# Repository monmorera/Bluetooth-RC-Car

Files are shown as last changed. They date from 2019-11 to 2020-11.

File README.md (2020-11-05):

# Bluetooth-RC-Car
### Bluetooth RC Car project for ECE 196 course

#### About:
This project is to create a bluetooth radio-controlled car. The PCB for the vehicle and remote was created and designed with EAGLE. It was then programmed using Arduino. The remote casing and vehicle parts were created and assembled in SolidWorks. Some parts were 3D printed and others laser cut.

##### Vehicle:
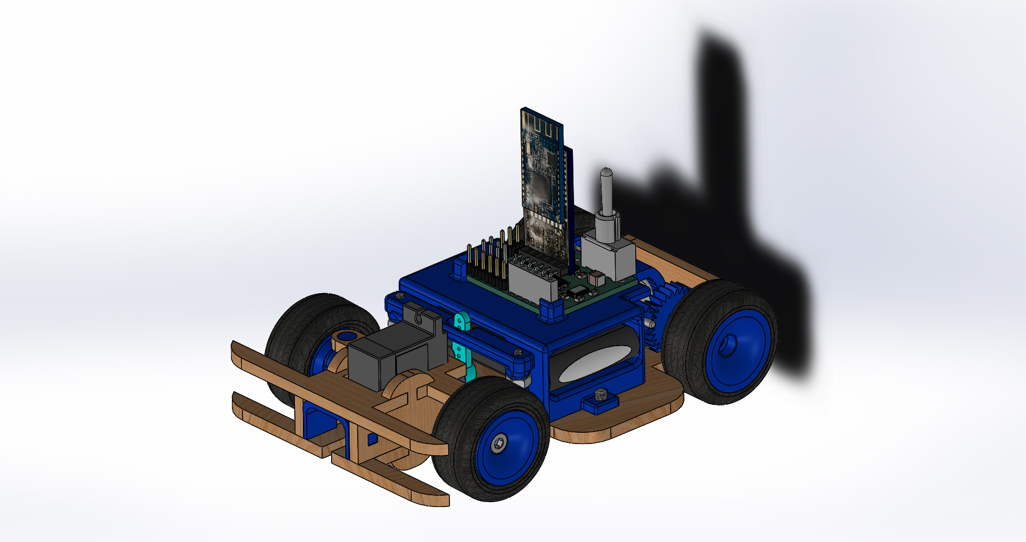
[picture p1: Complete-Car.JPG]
Vehicle


##### Remote:
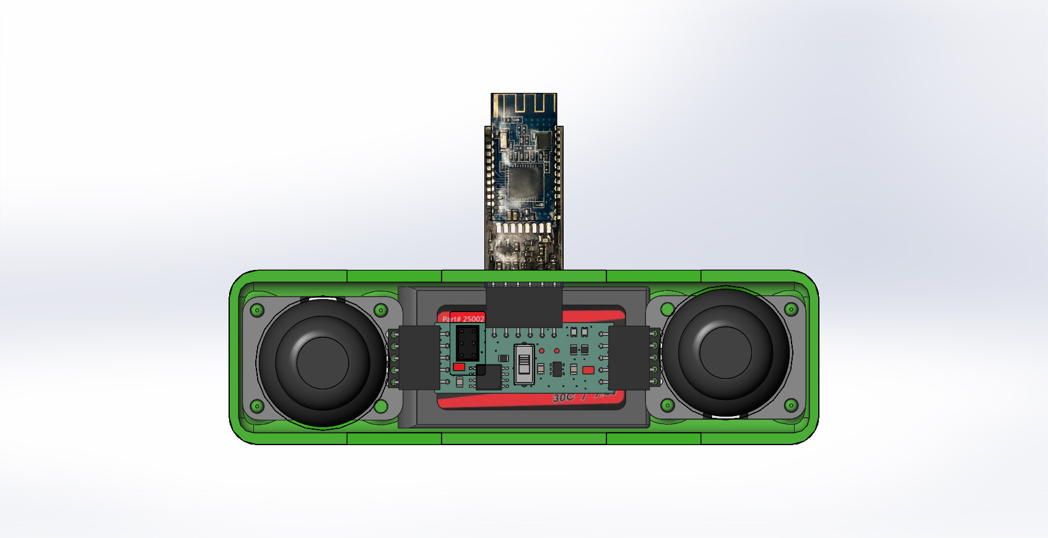
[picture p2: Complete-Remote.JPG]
Remote


##### Final:
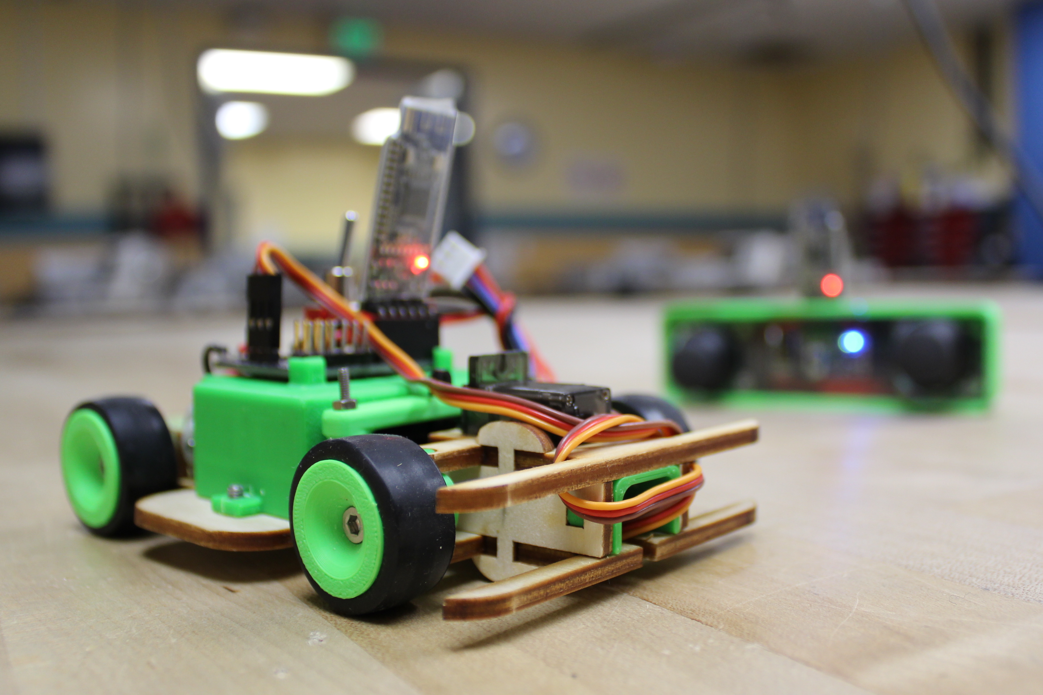
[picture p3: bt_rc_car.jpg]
Final


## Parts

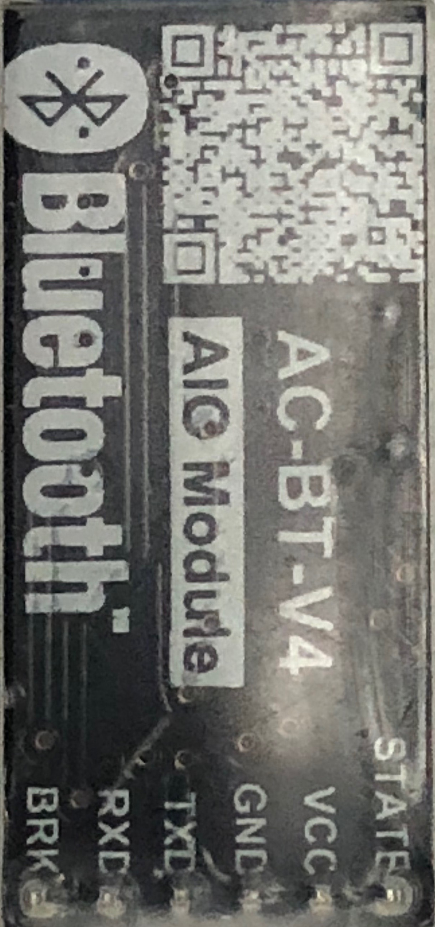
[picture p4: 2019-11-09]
SolidWorks/AddOn_model_parts/Bluetooth_RC/bluetooth_back.JPG

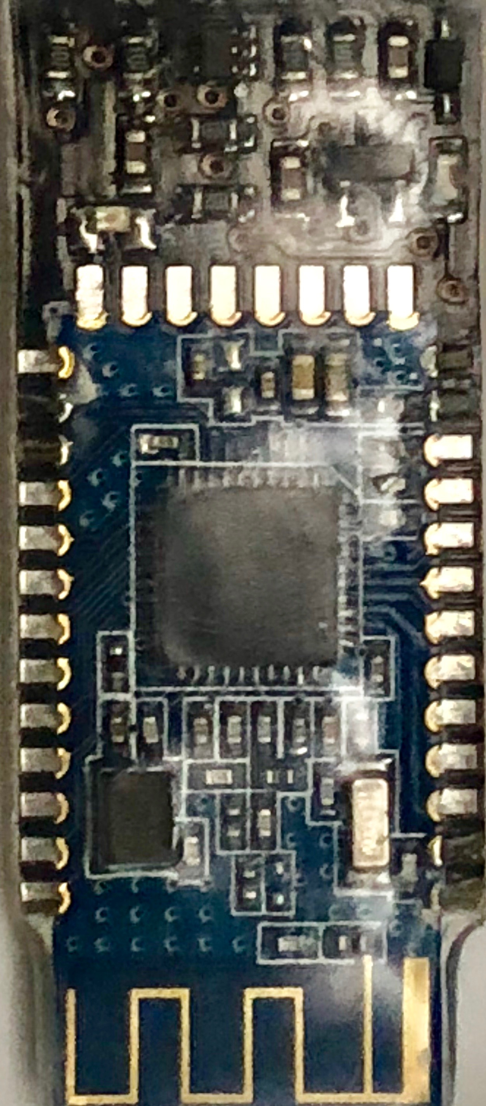
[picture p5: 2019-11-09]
SolidWorks/AddOn_model_parts/Bluetooth_RC/bluetooth_front.JPG

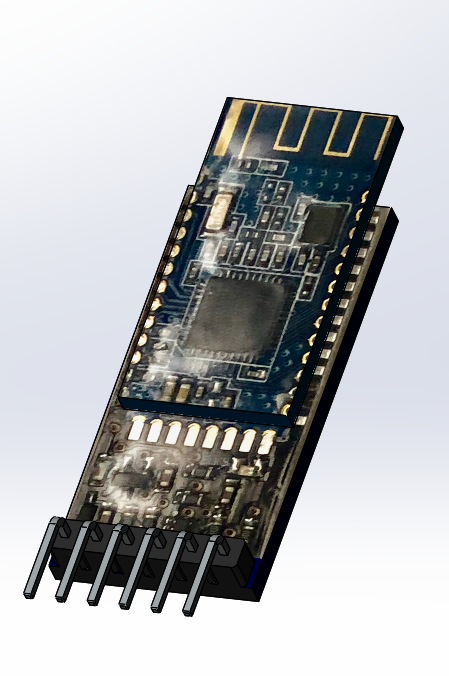
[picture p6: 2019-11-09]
SolidWorks/AddOn_model_parts/Bluetooth_RC/blue.PNG

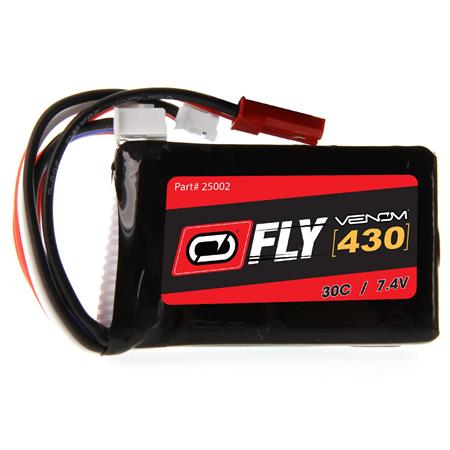
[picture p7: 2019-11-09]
SolidWorks/AddOn_model_parts/ven25002.jpg

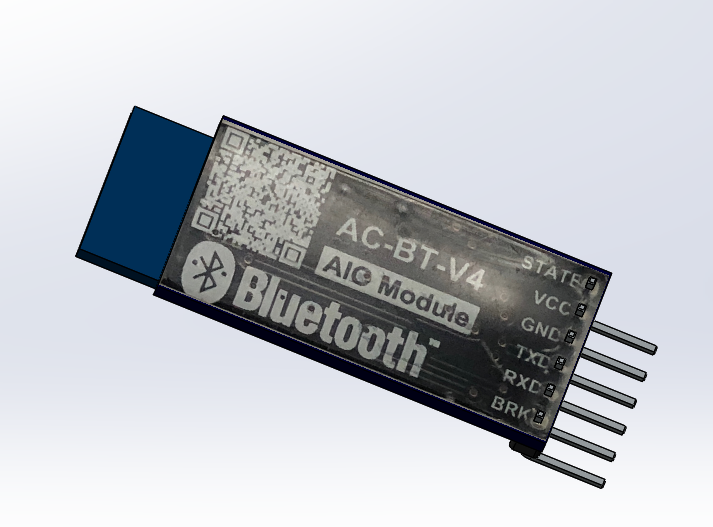
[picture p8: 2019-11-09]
SolidWorks/AddOn_model_parts/Bluetooth_RC/blue_back.PNG

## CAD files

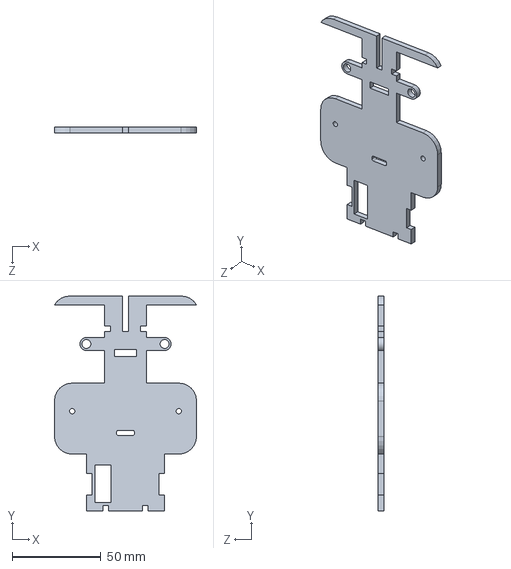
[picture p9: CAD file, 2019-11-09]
SolidWorks/Main Frame.SLDPRT
80.0 x 121.0 x 3.12 mm

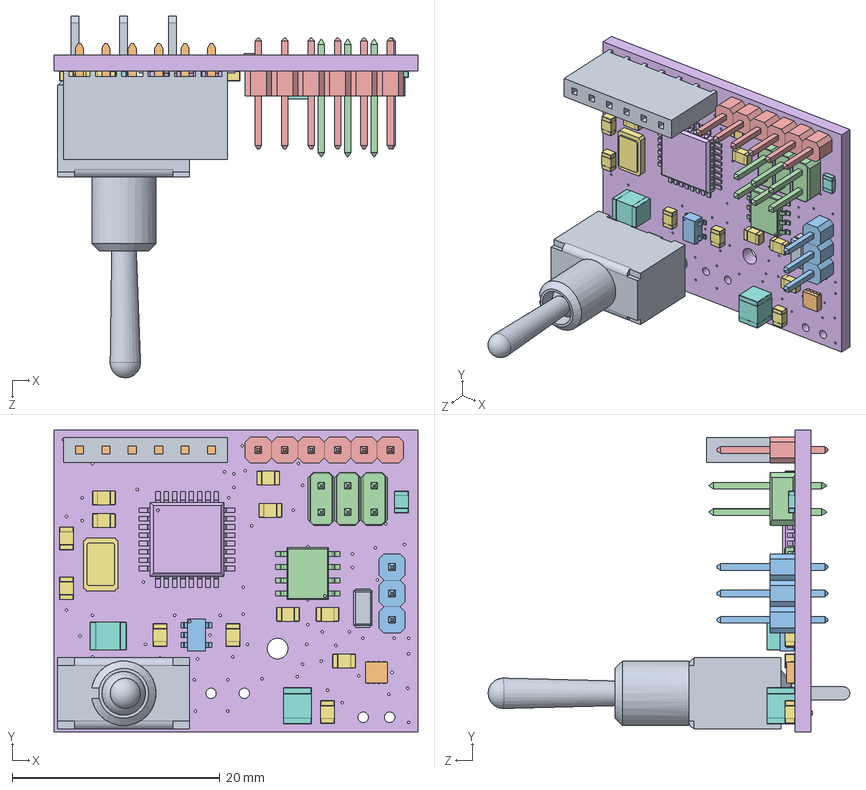
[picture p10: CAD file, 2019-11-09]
SolidWorks/vehicle.SLDASM
35.0 x 29.0 x 34.8 mm
_SSW-106-01-S-S_terminal.step
_SSW-106-01-S-S_pin.step
P(B,C)C01SAAN (1).step x 3
Dual TH withbump format.step x 3
P(B,C)C01SAAN.step x 6
Board.step
1uF_25V.step x 12
10K.step
5A_28V.step
DRV8838D 1.8A.step
MCP1802T-500 300mA_5V.step
BD60GC0WEFJ 1A_6V.step
2PT_GND_TIE.step
ATMEGA328p.step
16 MHz.step
100uF_16V.step x 2
10uF_16V.step

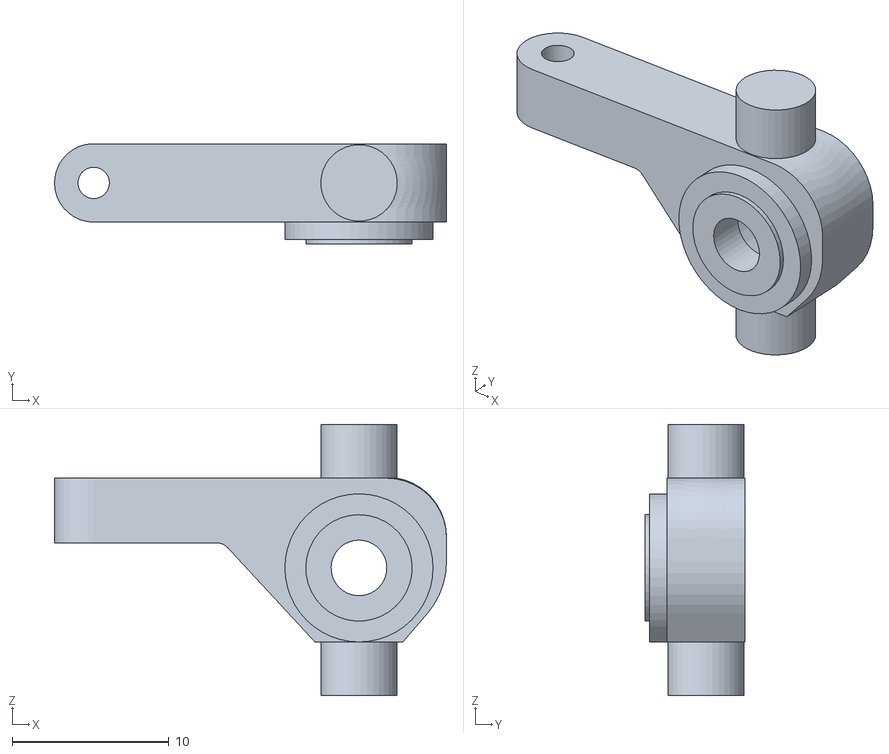
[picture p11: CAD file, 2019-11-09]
SolidWorks/3D print parts of car/ExtendedFrontAxleRightV4.STL
25.0 x 6.41 x 17.3

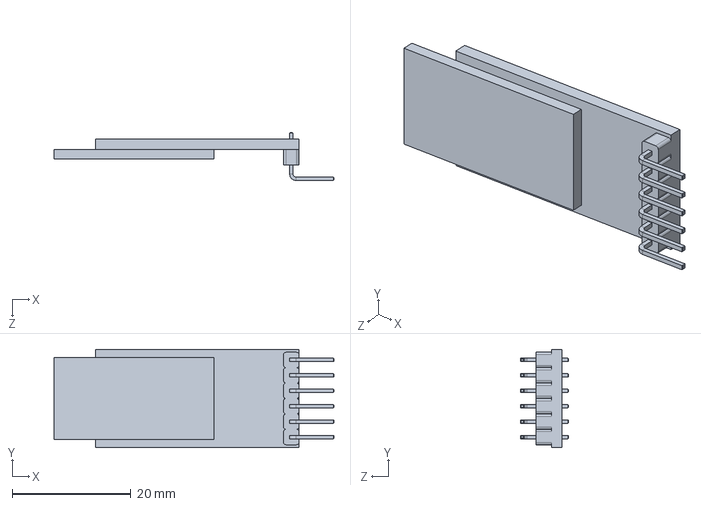
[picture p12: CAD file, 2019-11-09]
SolidWorks/AddOn_model_parts/Bluetooth_RC/Bluetooth_RC.SLDPRT
47.2 x 16.6 x 8.10 mm

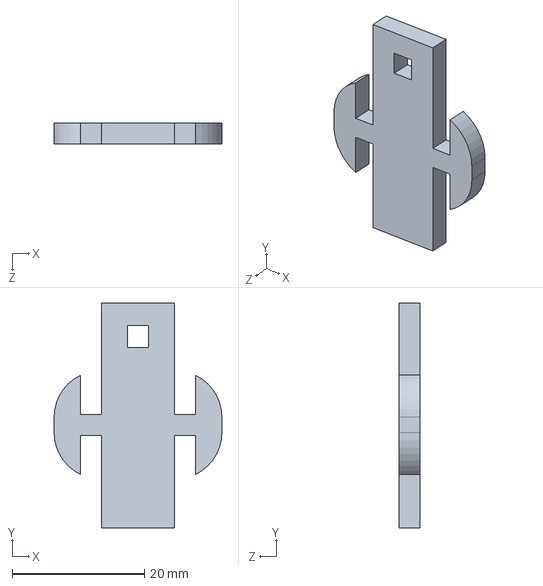
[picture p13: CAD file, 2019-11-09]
SolidWorks/CarFramePartA.SLDPRT
25.4 x 34.0 x 3.12 mm

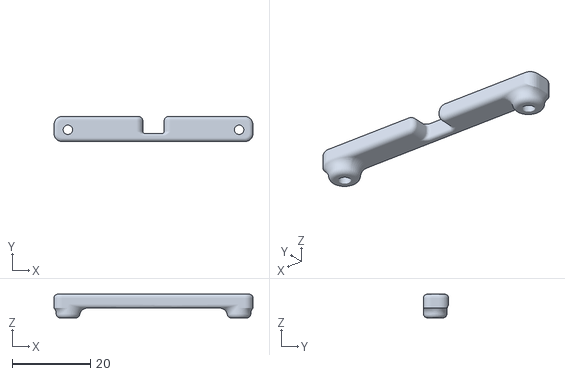
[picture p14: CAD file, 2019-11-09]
SolidWorks/3D print parts of car/ServoMountV7.STL
51.0 x 6.40 x 6.10

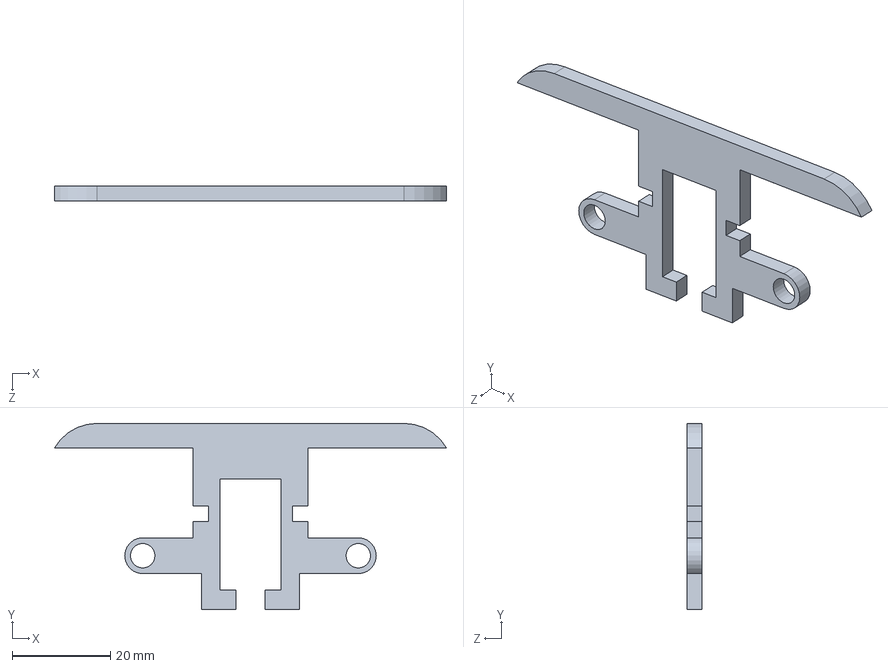
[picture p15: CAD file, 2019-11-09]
SolidWorks/CarFramePartD.SLDPRT
80.0 x 38.0 x 3.12 mm

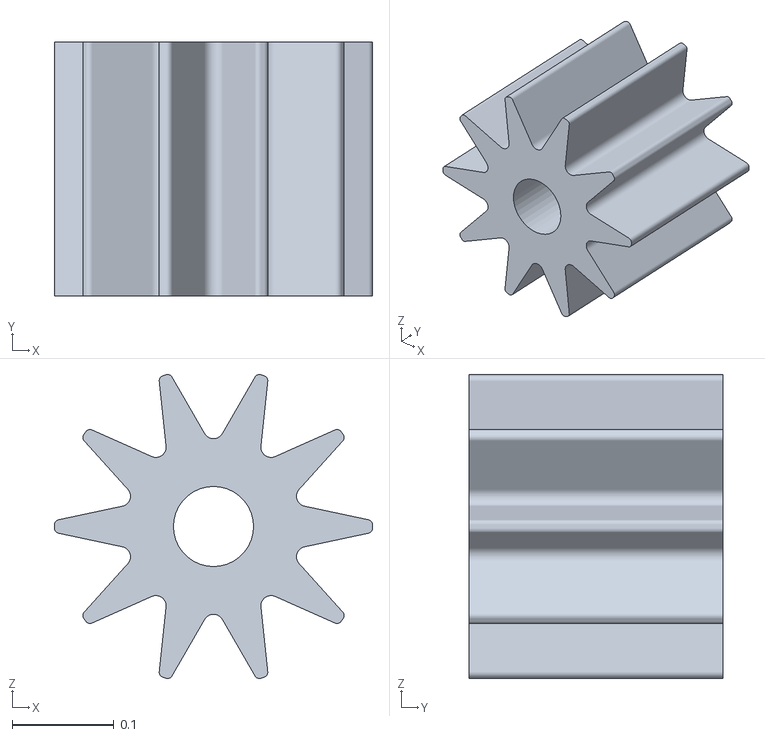
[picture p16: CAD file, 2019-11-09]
SolidWorks/3D print parts of car/motor_gear.STL
0.312 x 0.25 x 0.299

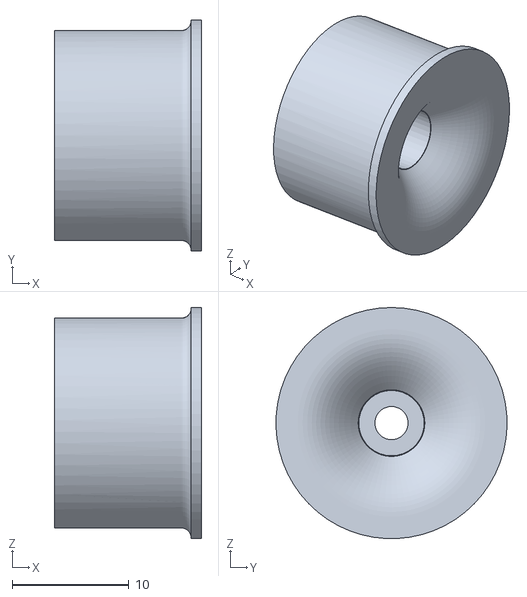
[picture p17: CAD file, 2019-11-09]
SolidWorks/3D print parts of car/FrontWheelV7.STL
12.6 x 19.8 x 19.8

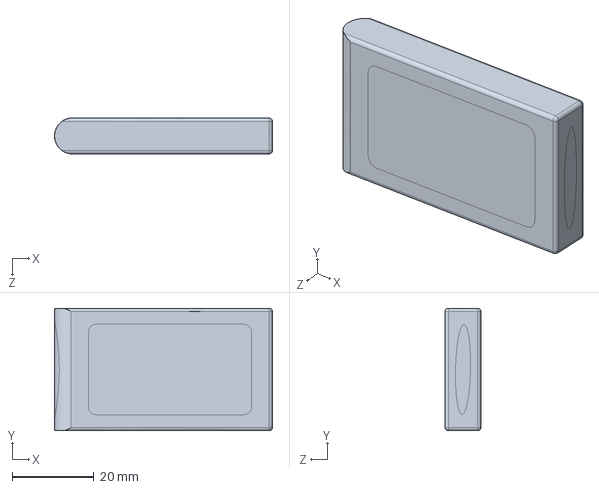
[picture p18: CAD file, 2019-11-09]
SolidWorks/AddOn_model_parts/Battery.SLDPRT
53.4 x 30.0 x 8.81 mm

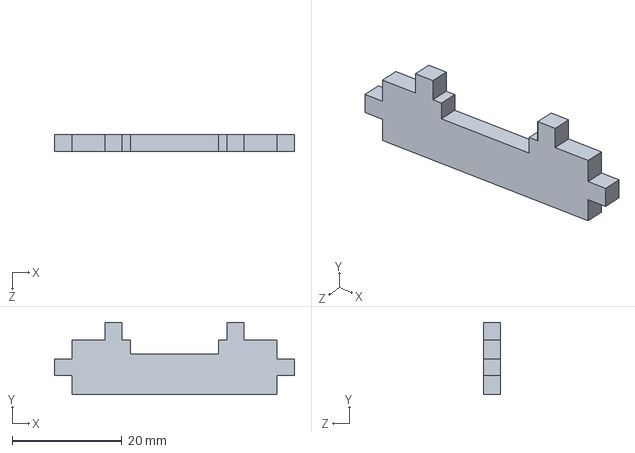
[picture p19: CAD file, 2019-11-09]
SolidWorks/CarFramePartC.SLDPRT
43.8 x 13.2 x 3.12 mm

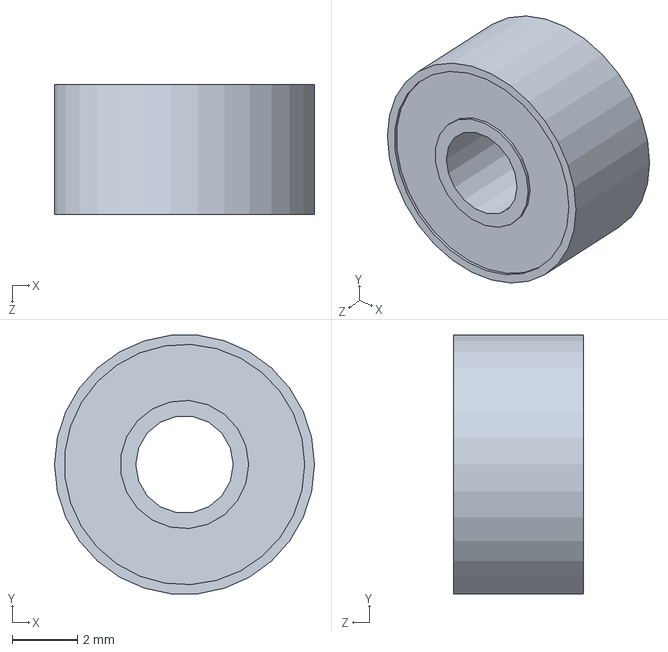
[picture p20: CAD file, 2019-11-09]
SolidWorks/AddOn_model_parts/Bearing.SLDPRT
8.00 x 7.96 x 4.00 mm

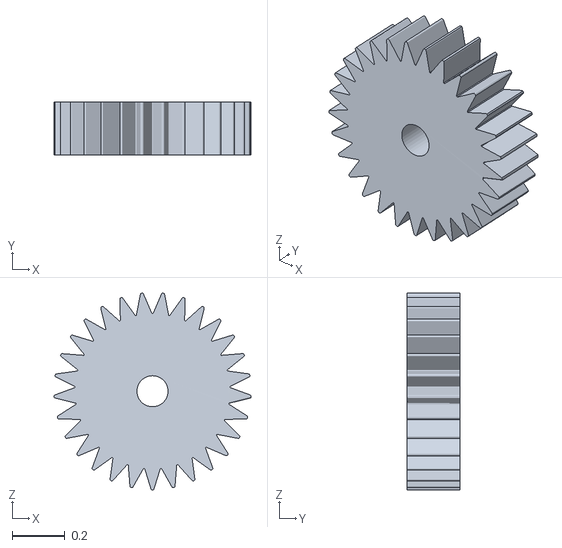
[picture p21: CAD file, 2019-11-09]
SolidWorks/3D print parts of car/driveGearV1.1.STL
0.749 x 0.2 x 0.748

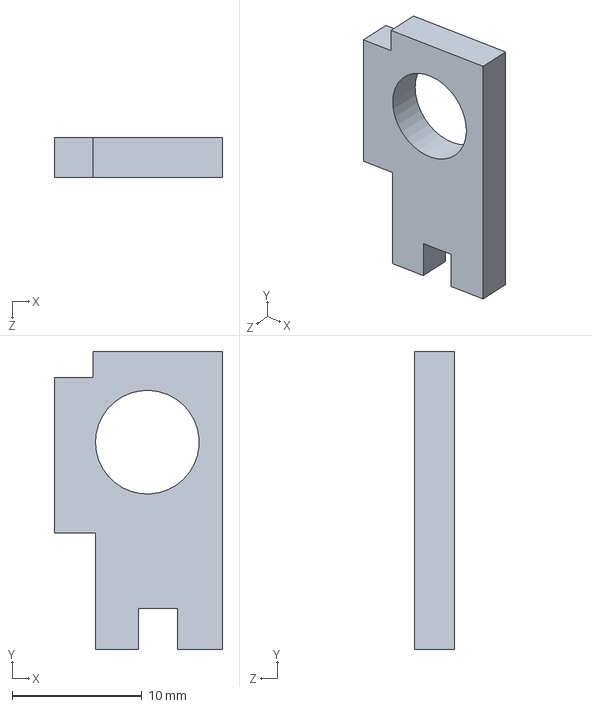
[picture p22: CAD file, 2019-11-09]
SolidWorks/CarFramePartB.SLDPRT
13.0 x 23.0 x 3.12 mm

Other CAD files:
SolidWorks/3D print parts of car/ExtendedFrontAxleLeftV4.STL
SolidWorks/3D print parts of car/PCBsupportV3.STL
SolidWorks/AddOn_model_parts/joy_stick_BTRC.SLDPRT
SolidWorks/3D print parts of car/motorMountV2.STL
SolidWorks/3D print parts of car/BackWheelV7.STL
SolidWorks/3D print parts of car/DCmotor_mountV4.STL
SolidWorks/3D print parts of car/FrontFlexConnectorV1.STL
SolidWorks/AddOn_model_parts/60mmBolt.SLDPRT
SolidWorks/AddOn_model_parts/BTRC DC motor.SLDPRT
SolidWorks/AddOn_model_parts/Buu tire v2.SLDPRT
SolidWorks/AddOn_model_parts/M2_nut.SLDPRT
SolidWorks/AddOn_model_parts/M2_washer.SLDPRT
SolidWorks/AddOn_model_parts/M2x14mm_Screw.SLDPRT
SolidWorks/AddOn_model_parts/M3_nut.SLDPRT
SolidWorks/AddOn_model_parts/M3_washer.SLDPRT
SolidWorks/AddOn_model_parts/M3x16mm_Screw.SLDPRT
SolidWorks/AddOn_model_parts/M3x60mm_Screw.SLDPRT
SolidWorks/AddOn_model_parts/M3x8mm_Screw.SLDPRT
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

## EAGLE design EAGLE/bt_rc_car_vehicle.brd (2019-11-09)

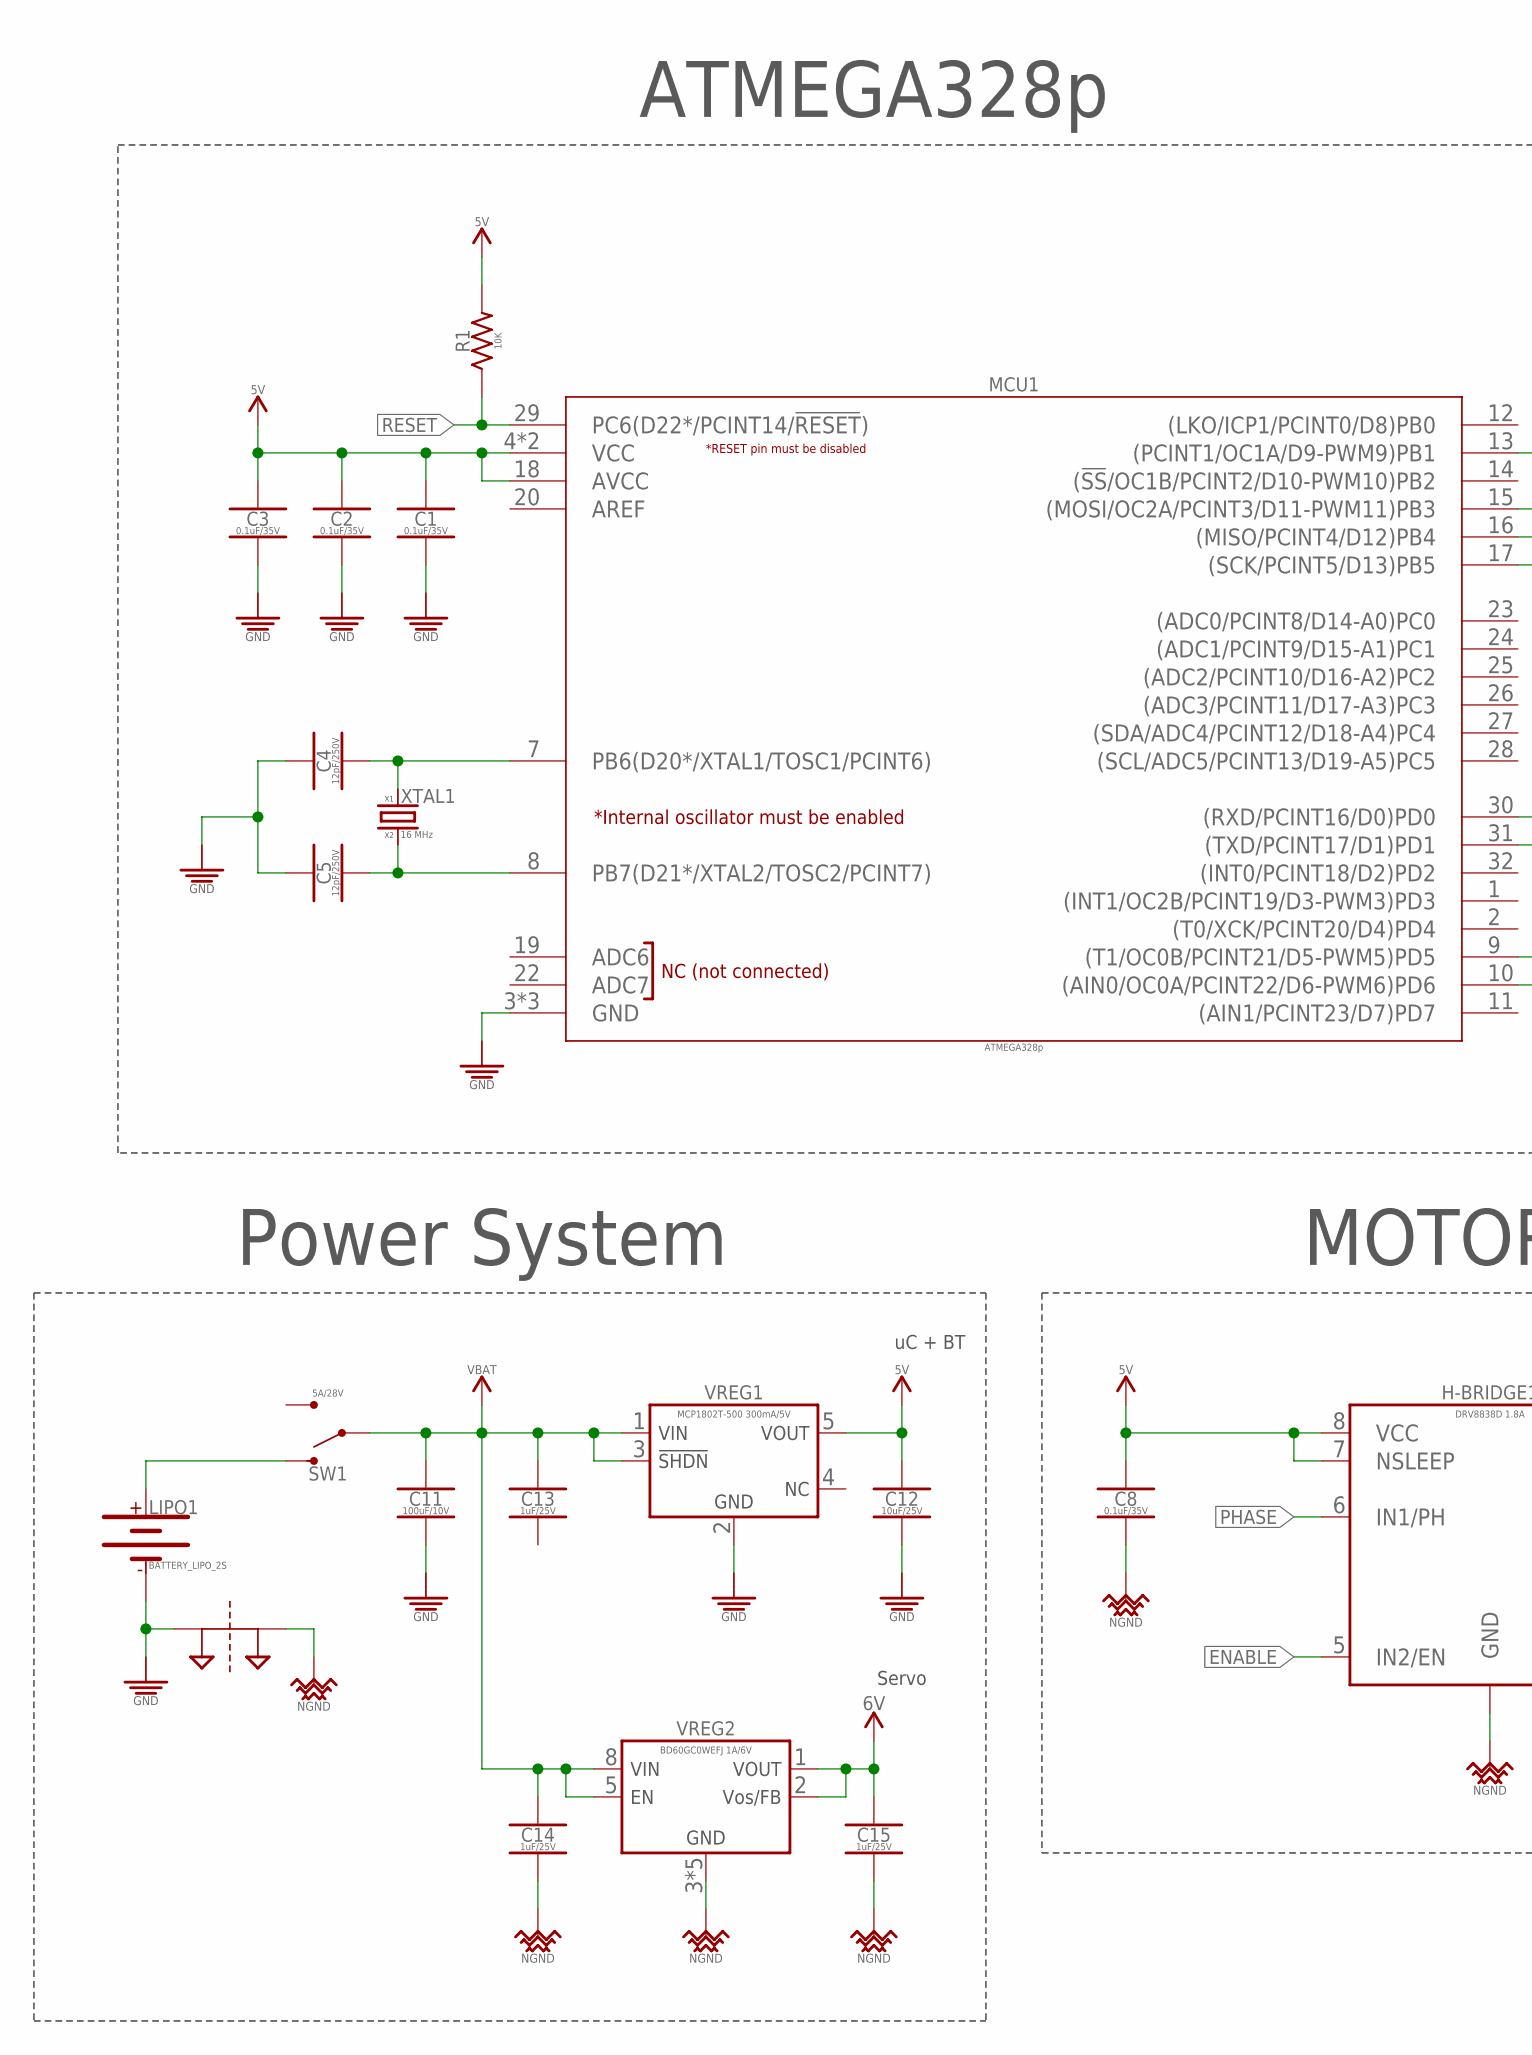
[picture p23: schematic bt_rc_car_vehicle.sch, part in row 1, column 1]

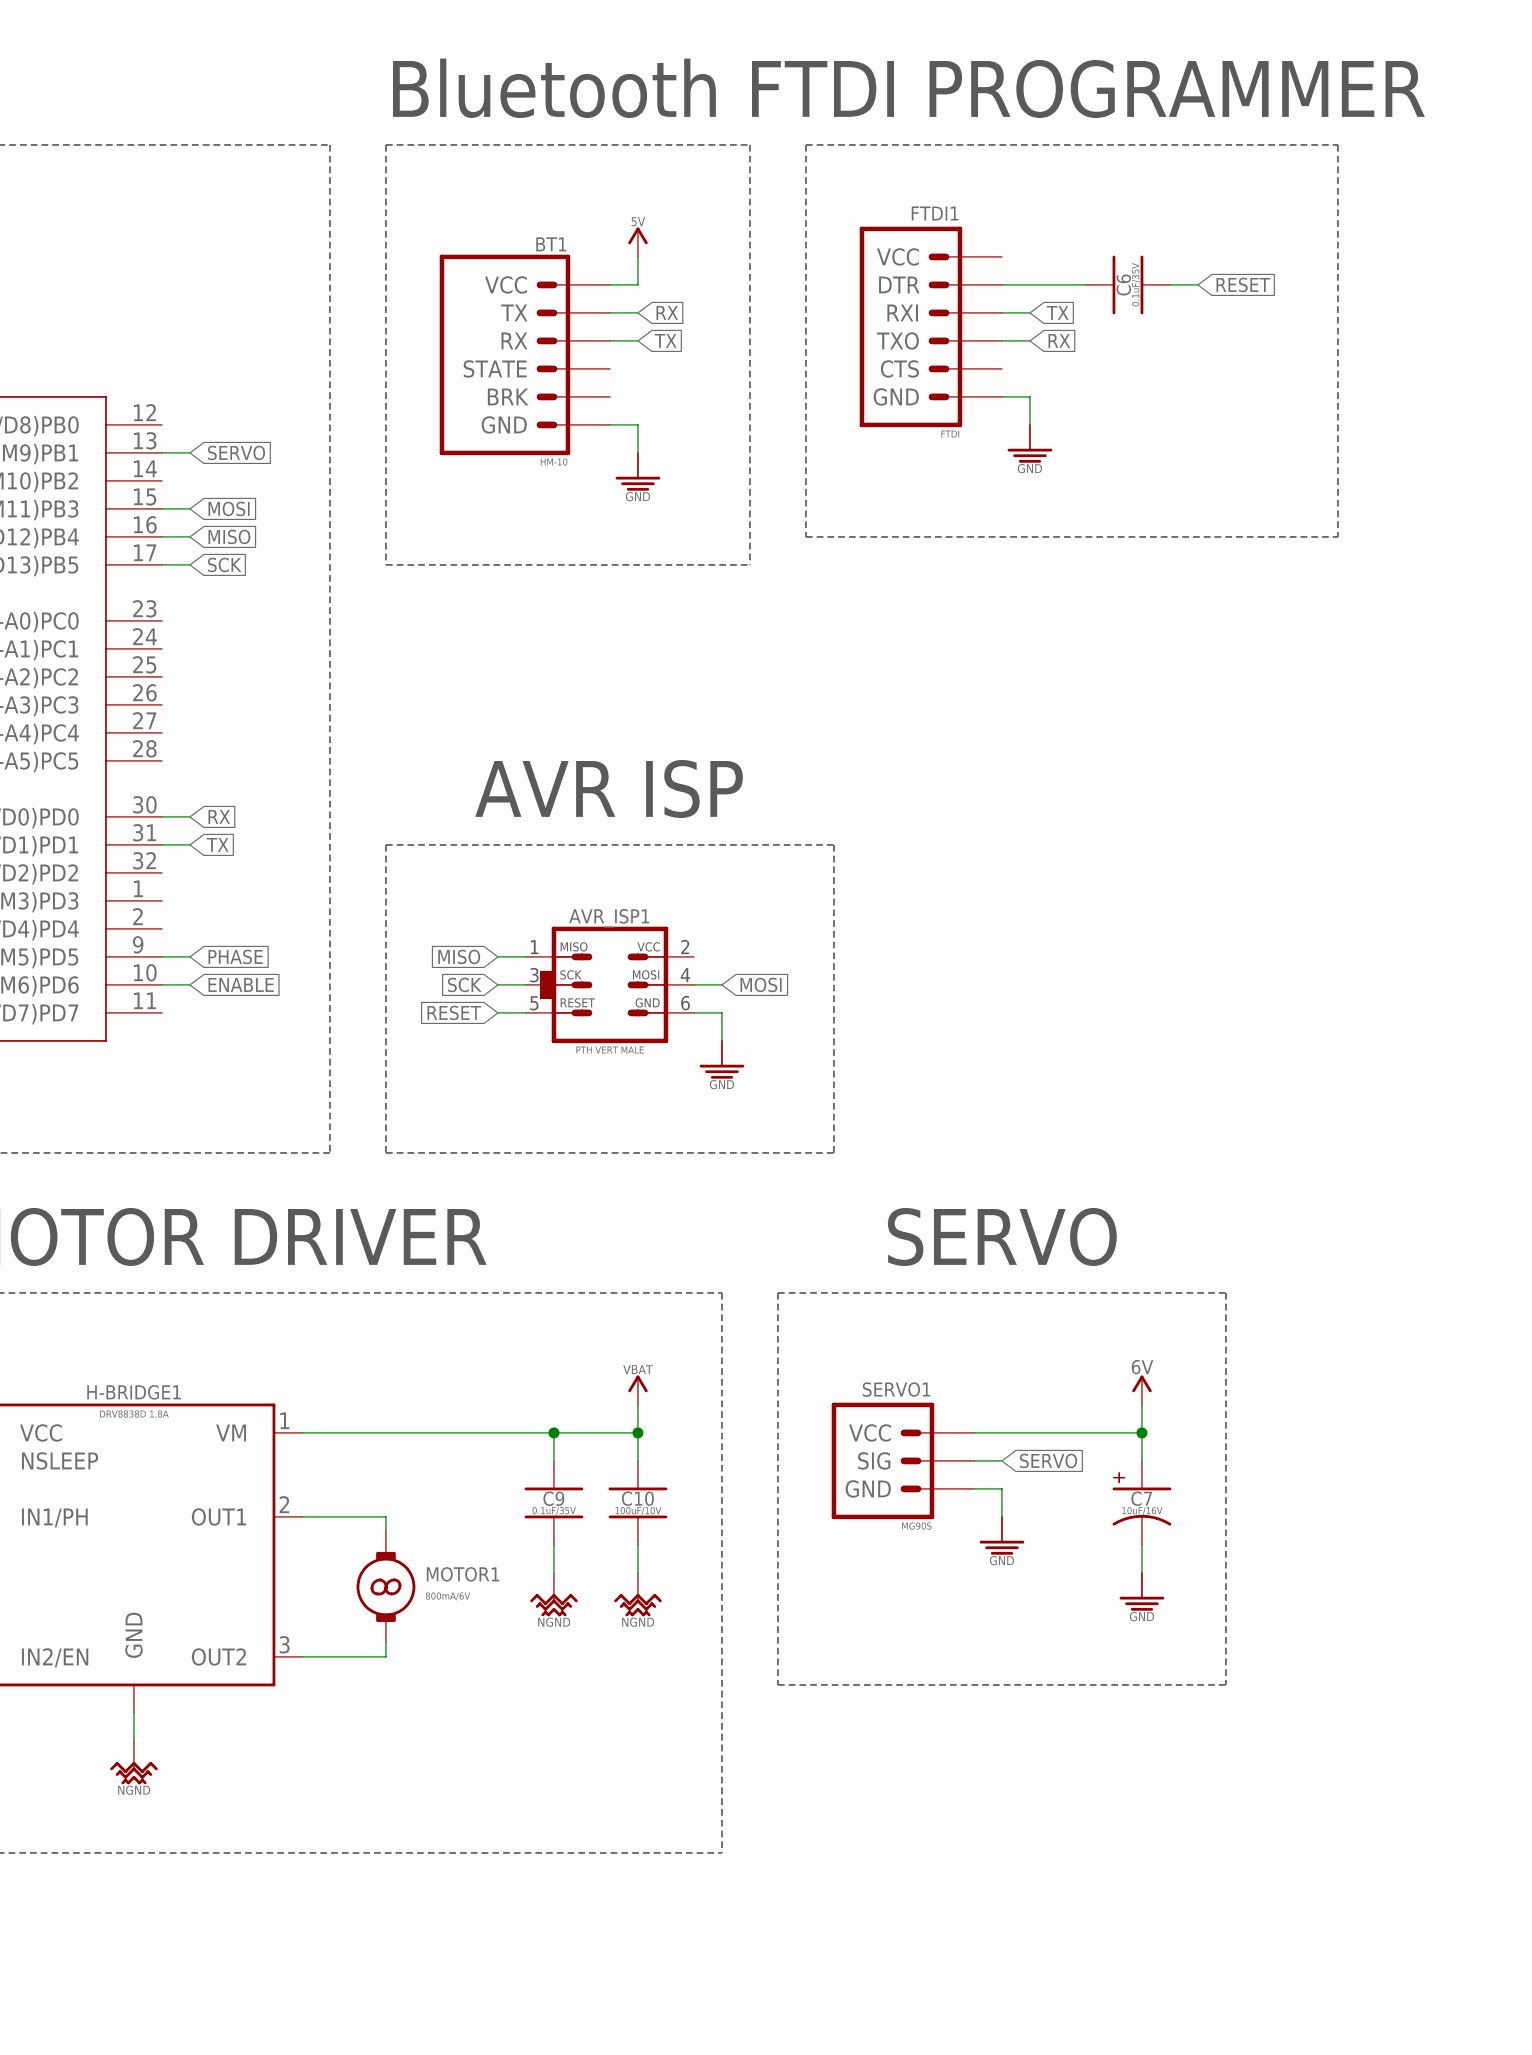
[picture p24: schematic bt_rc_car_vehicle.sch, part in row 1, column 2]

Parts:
AVR_ISP1: PTH VERT MALE; HDRV6W64P254_2X3_762X483X838B_AVR-ISP
BT1: HM-10; HDRVR6W64P254_1X6_1574X254X850B
C1, C2, C3, C6, C8, C9: 0.1uF/35V; CAPC2012X95_SMD-0805
C4, C5: 12pF/250V; CAPC2012X95_SMD-0805
C7: 10uF/16V; CAPMP3216X180_SMD_CAP-TANT-1206
C10, C11: 100uF/10V; CAPC3225X270_SMD-1210
C12: 10uF/25V; CAPC2012X95_SMD-0805
C13, C14, C15: 1uF/25V; CAPC2012X95_SMD-0805
FTDI1: FTDI; HDRV6W64P254_1X6_1524X254X838B_FTDI
H-BRIDGE1: DRV8838D 1.8A; WSON-8-PPAD
LIPO1: BATTERY_LIPO_2S; DUAL_PTH_PADS
MCU1: ATMEGA328p; QFP80P900X900X120-32
MOTOR1: 800mA/6V; CONNECTOR_MOTOR
NET_BRIDGE1: NET_BRIDGE
R1: 10K; RESC2012X60_SMD-0805
SERVO1: MG90S; HDRV3W64P254_1X3_762X254X838B
SW1: 5A/28V; SW_TOGGLE_SPDT_5A-28V_13L-7W
VREG1: MCP1802T-500 300mA/5V; SOT95P280X145-5
VREG2: BD60GC0WEFJ 1A/6V; SOIC127P600X100-8
XTAL1: 16 MHz; OSCCC500X320X110_CRYSTAL

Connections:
5V: BT1.VCC, C1.1, C2.1, C3.1, C8.1, C12.1, H-BRIDGE1.7 (NSLEEP), H-BRIDGE1.8 (VCC), MCU1.4 (VCC), MCU1.6 (VCC), MCU1.18 (AVCC), R1.2, VREG1.5 (VOUT)
6V: C7.A, C15.1, SERVO1.VCC, VREG2.1 (VOUT), VREG2.2 (VOS/FB)
ENABLE: H-BRIDGE1.5 (IN2/EN), MCU1.10 ((AIN0/OC0A/PCINT22/D6-PWM6)PD6)
GND: AVR_ISP1.GND, BT1.GND, C1.2, C2.2, C3.2, C4.1, C5.1, C7.K, C11.2, C12.2, FTDI1.GND, LIPO1.-, MCU1.3 (GND), MCU1.5 (GND), MCU1.21 (GND), NET_BRIDGE1.P$1, SERVO1.GND, VREG1.2 (GND)
MISO: AVR_ISP1.MISO, MCU1.16 ((MISO/PCINT4/D12)PB4)
MOSI: AVR_ISP1.MOSI, MCU1.15 ((MOSI/OC2A/PCINT3/D11-PWM11)PB3)
unnamed: C5.2, MCU1.8 (PB7(D21*/XTAL2/TOSC2/PCINT7)), XTAL1.3 (XTAL2)
unnamed: C4.2, MCU1.7 (PB6(D20*/XTAL1/TOSC1/PCINT6)), XTAL1.1 (XTAL1)
unnamed: C6.1, FTDI1.DTR
unnamed: H-BRIDGE1.2 (OUT1), MOTOR1.+
unnamed: H-BRIDGE1.3 (OUT2), MOTOR1.-
unnamed: LIPO1.+, SW1.S1
NGND: C8.2, C9.2, C10.2, C14.2, C15.2, H-BRIDGE1.4 (GND), H-BRIDGE1.GND, H-BRIDGE1.P$1 (GND), H-BRIDGE1.P$2 (GND), NET_BRIDGE1.P$2, VREG2.3 (GND), VREG2.4 (GND), VREG2.6 (GND), VREG2.7 (GND), VREG2.FIN (GND)
PHASE: H-BRIDGE1.6 (IN1/PH), MCU1.9 ((T1/OC0B/PCINT21/D5-PWM5)PD5)
RESET: AVR_ISP1.RESET, C6.2, MCU1.29 (PC6(D22*/PCINT14/!RESET!)), R1.1
RX: BT1.TX, FTDI1.TX (TXO), MCU1.30 ((RXD/PCINT16/D0)PD0)
SCK: AVR_ISP1.SCK, MCU1.17 ((SCK/PCINT5/D13)PB5)
SERVO: MCU1.13 ((PCINT1/OC1A/D9-PWM9)PB1), SERVO1.SIG
TX: BT1.RX, FTDI1.RX (RXI), MCU1.31 ((TXD/PCINT17/D1)PD1)
VBAT: C9.1, C10.1, C11.1, C13.1, C14.1, H-BRIDGE1.1 (VM), SW1.P, VREG1.1 (VIN), VREG1.3 (!SHDN), VREG2.5 (EN), VREG2.8 (VIN)

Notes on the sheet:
ATMEGA328p
Bluetooth
AVR ISP
FTDI PROGRAMMER
SERVO
MOTOR DRIVER
Power System
Servo
uC + BT

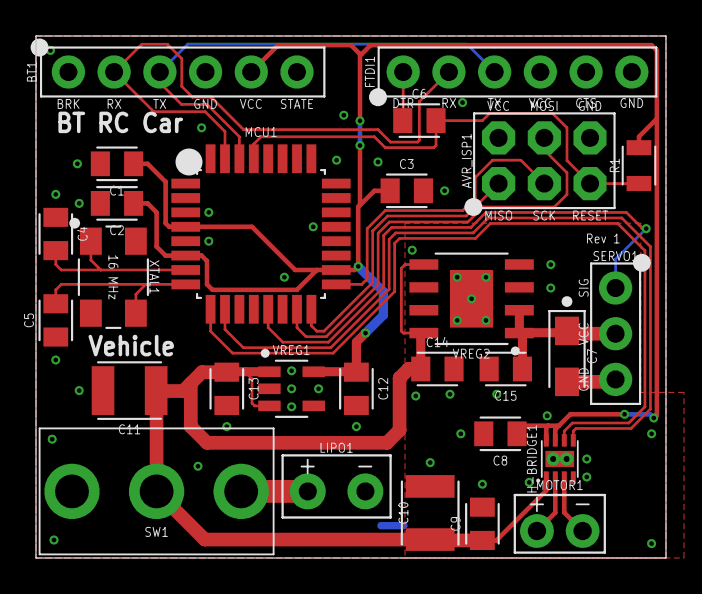
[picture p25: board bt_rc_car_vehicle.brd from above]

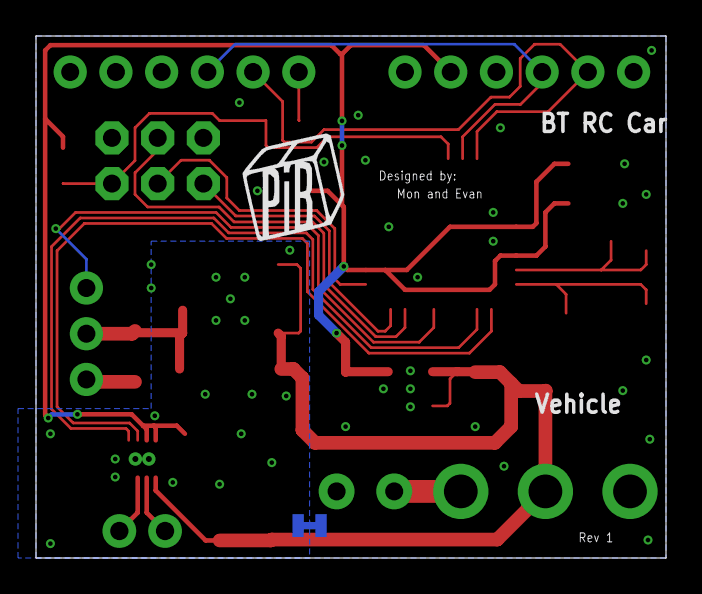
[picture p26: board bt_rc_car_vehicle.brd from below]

Board: 2 copper layers, 35.0 x 29.0 mm, 30 parts (2 on the bottom side), 20 nets.

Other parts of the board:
U$1: PIB_LOGO_10MM

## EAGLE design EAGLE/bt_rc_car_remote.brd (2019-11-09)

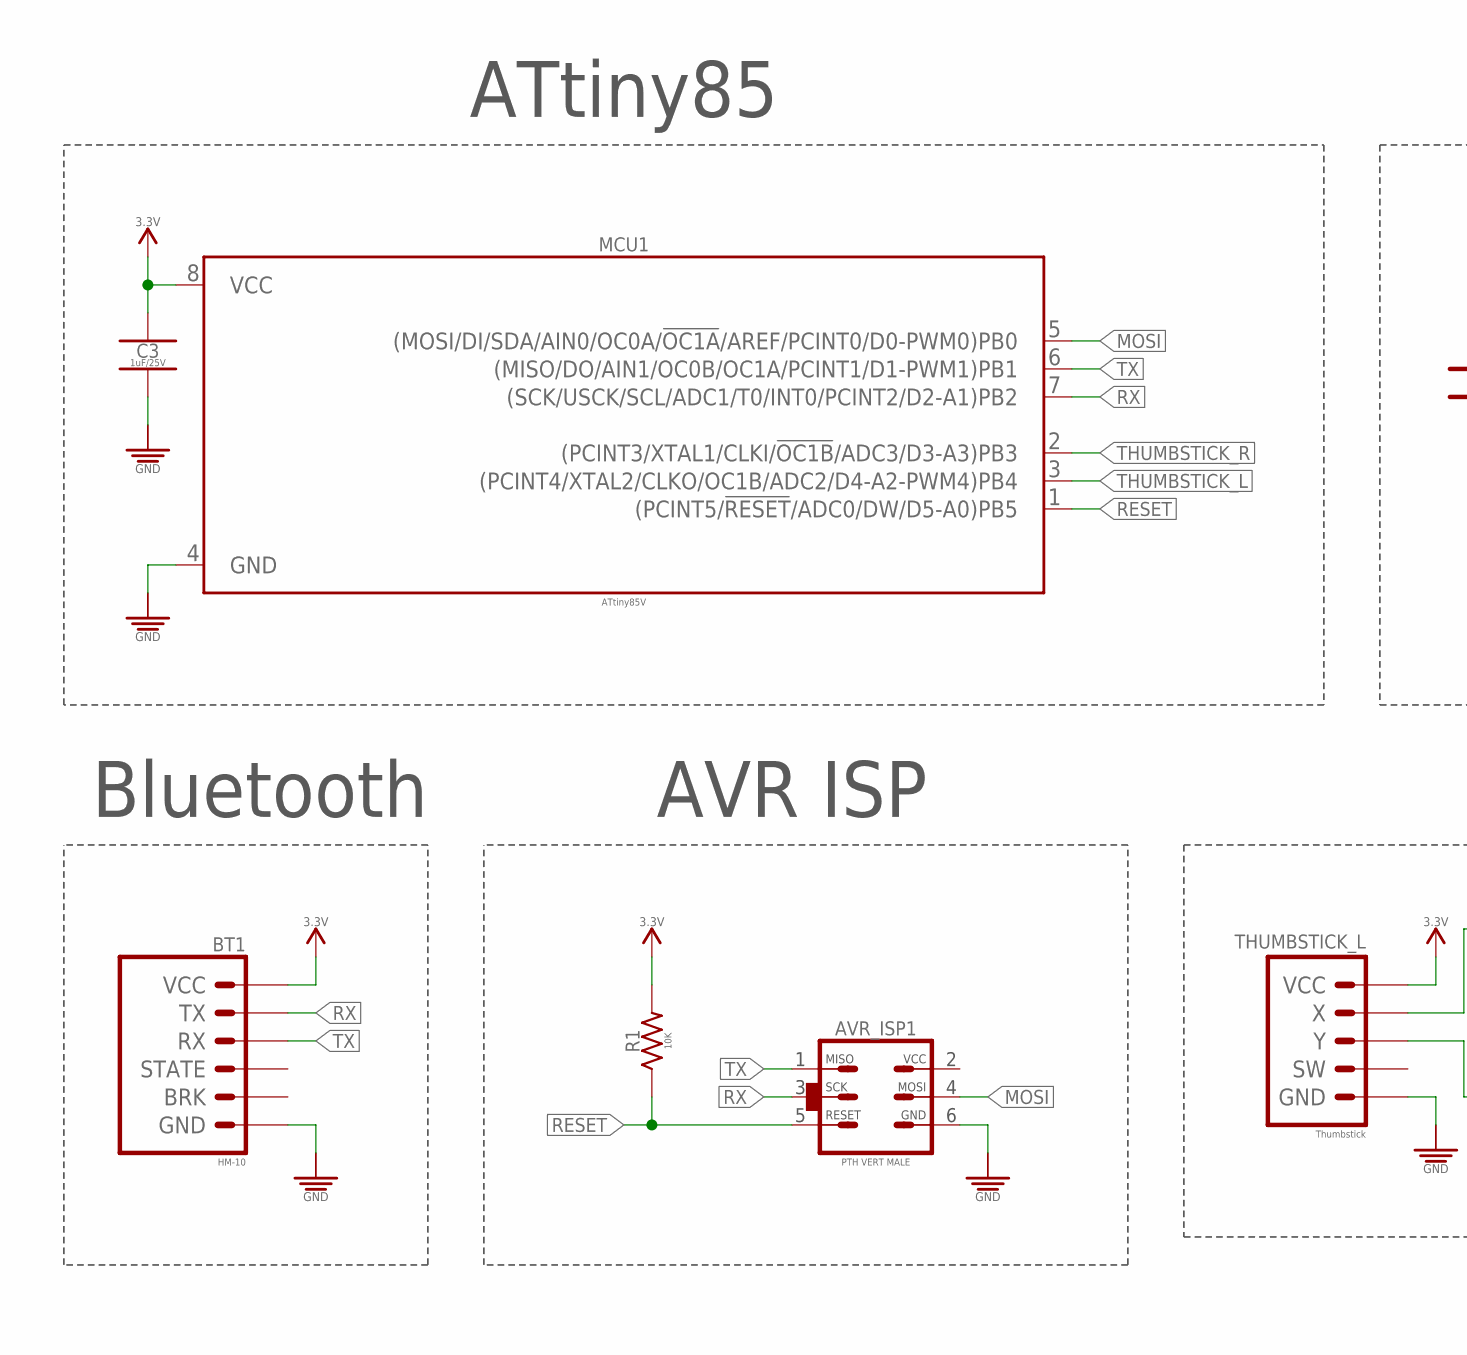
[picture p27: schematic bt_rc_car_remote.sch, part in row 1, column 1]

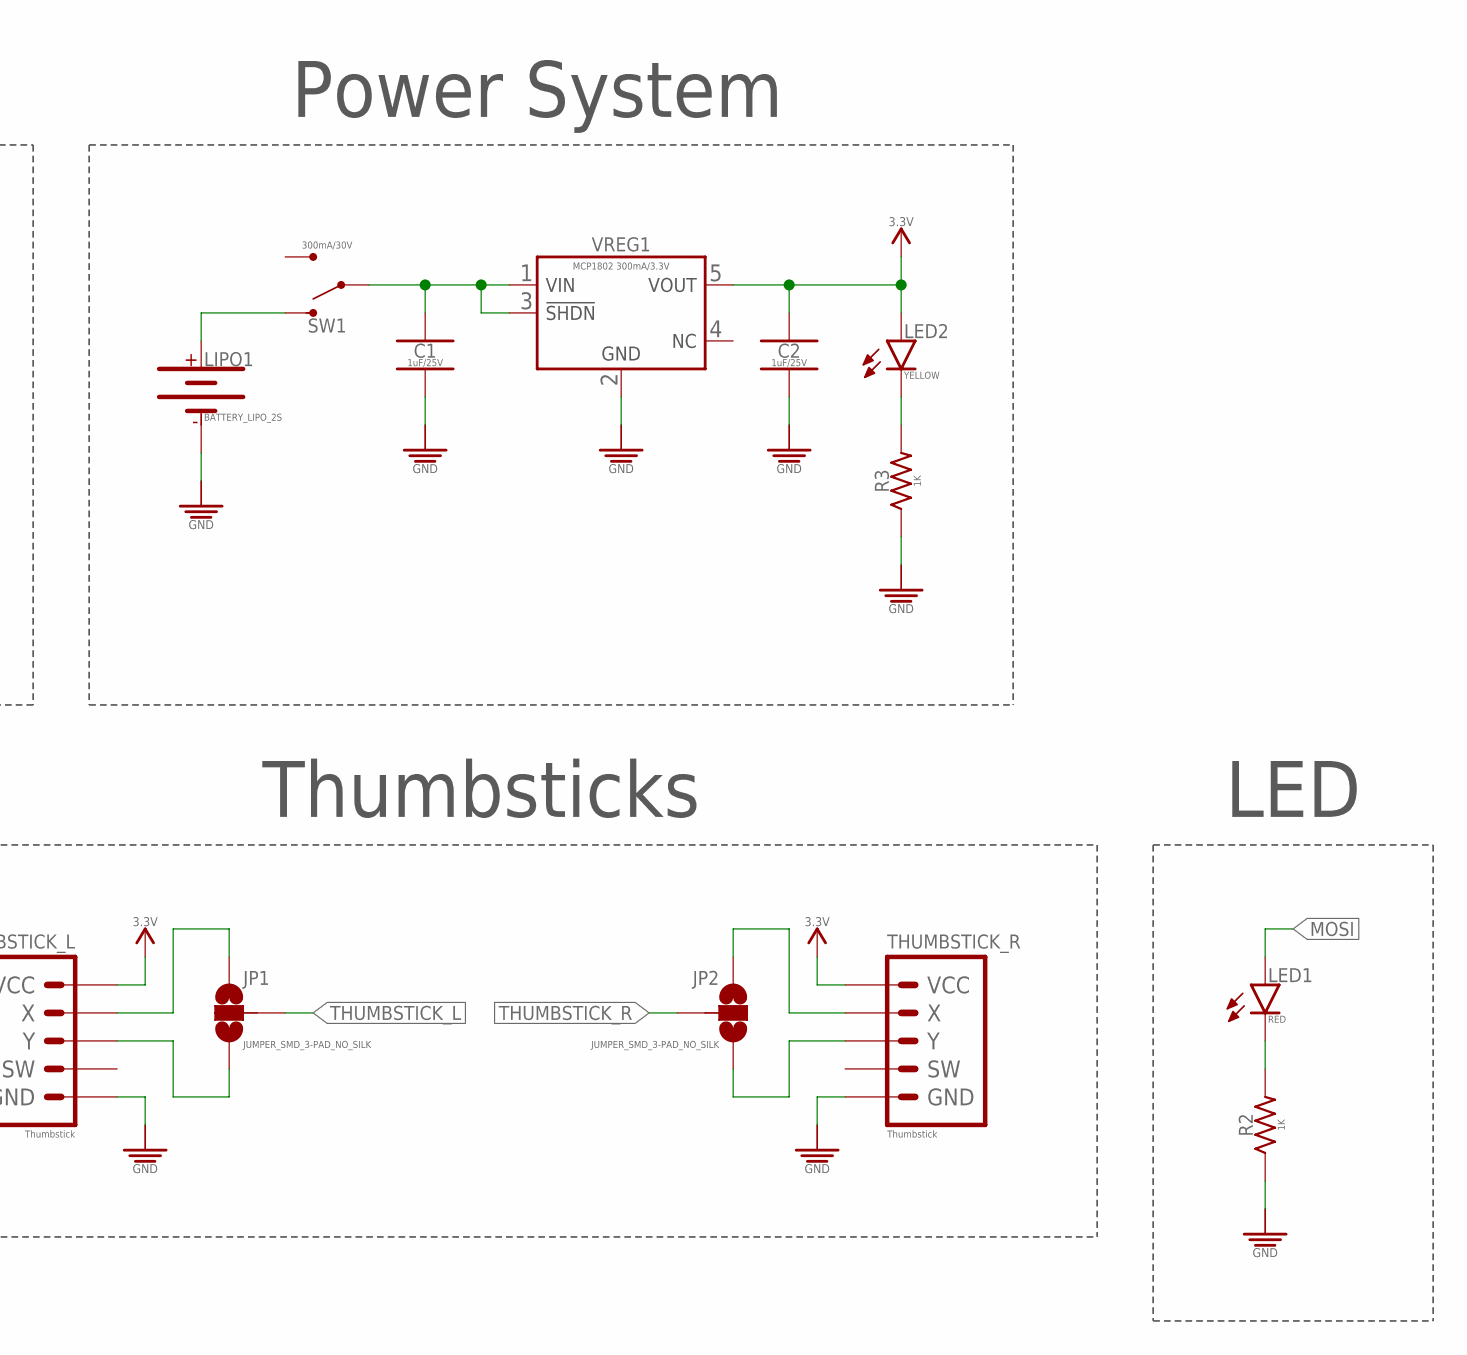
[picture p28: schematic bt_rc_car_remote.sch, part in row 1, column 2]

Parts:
AVR_ISP1: PTH VERT MALE; HDRV6W64P254_2X3_762X483X838B_AVR-ISP
BT1: HM-10; HDRRAR6W60P254_1X6_1574X850X274B
C1, C2, C3: 1uF/25V; CAPC2012X95_SMD-0805
JP1, JP2: JUMPER_SMD_3-PAD_NO_SILK; SMT-JUMPER_3_NO_SILK
LED1: RED; LEDC2012X120_LED-0805
LED2: YELLOW; LEDC2012X120_LED-0805
LIPO1: BATTERY_LIPO_2S; DUAL_PTH_PADS
MCU1: ATtiny85V; SOIC127P798X216-8
R1: 10K; RESC2012X60_SMD-0805
R2, R3: 1K; RESC2012X60_SMD-0805
SW1: 300mA/30V; SW_SLIDE_SPDT_VERT_8.6L-4.3W
THUMBSTICK_L: Thumbstick; HDRRAR5W60P254_1X5_1320X850X274B
THUMBSTICK_R: Thumbstick; HDRRAR5W60P254_1X5_1320X850X274B
VREG1: MCP1802 300mA/3.3V; SOT95P280X145-5

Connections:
3.3V: BT1.VCC, C2.1, C3.1, LED2.A, MCU1.8 (VCC), R1.2, THUMBSTICK_L.VCC, THUMBSTICK_R.VCC, VREG1.5 (VOUT)
GND: AVR_ISP1.GND, BT1.GND, C1.2, C2.2, C3.2, LIPO1.-, MCU1.4 (GND), R2.1, R3.1, THUMBSTICK_L.GND, THUMBSTICK_R.GND, VREG1.2 (GND)
MOSI: AVR_ISP1.MOSI, LED1.A, MCU1.5 ((MOSI/DI/SDA/AIN0/OC0A/!OC1A!/AREF/PCIN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)
unnamed: JP1.1, THUMBSTICK_L.X
unnamed: JP1.3, THUMBSTICK_L.Y
unnamed: JP2.1, THUMBSTICK_R.X
unnamed: JP2.3, THUMBSTICK_R.Y
unnamed: LED1.K, R2.2
unnamed: LIPO1.+, SW1.S1
unnamed: C1.1, SW1.P, VREG1.1 (VIN), VREG1.3 (!SHDN)
unnamed: LED2.K, R3.2
RESET: AVR_ISP1.RESET, MCU1.1 ((PCINT5/!RESET!/ADC0/DW/D5-A0)PB5), R1.1
RX: AVR_ISP1.SCK, BT1.TX, MCU1.7 ((SCK/USCK/SCL/ADC1/T0/INT0/PCINT2/D2-A1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)
THUMBSTICK_L: JP1.2, MCU1.3 ((PCINT4/XTAL2/CLKO/OC1B/ADC2/D4-A2-PWM4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)
THUMBSTICK_R: JP2.2, MCU1.2 ((PCINT3/XTAL1/CLKI/!OC1B!/ADC3/D3-A3)PB3)
TX: AVR_ISP1.MISO, BT1.RX, MCU1.6 ((MISO/DO/AIN1/OC0B/OC1A/PCINT1/D1-PWM1)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)

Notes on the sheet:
ATtiny85
Thumbsticks
Bluetooth
AVR ISP
LED
Power System

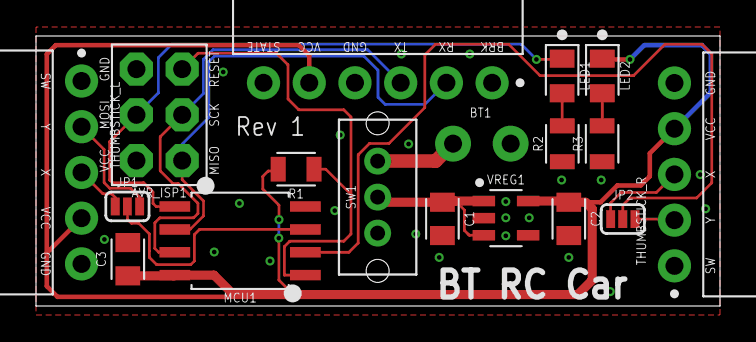
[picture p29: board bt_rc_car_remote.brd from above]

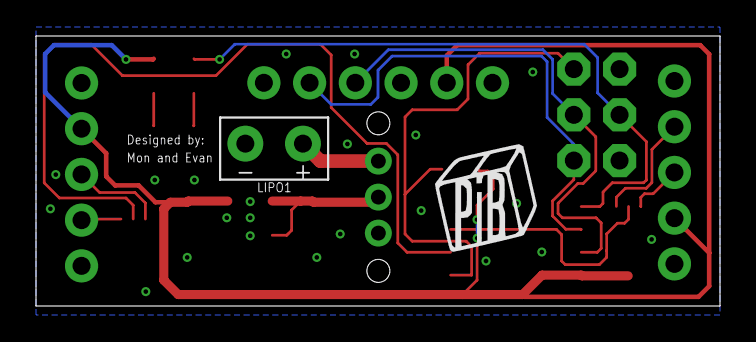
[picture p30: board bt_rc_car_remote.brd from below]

Board: 2 copper layers, 38.0 x 15.0 mm, 19 parts (2 on the bottom side), 16 nets.

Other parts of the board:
U$1: PIB_LOGO_10MM

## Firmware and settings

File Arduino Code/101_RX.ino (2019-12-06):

// Custom one-way communication with Bluetooth HM-10
// Receiving data in the form of a struct from transmitter
//
// Reads from the software UART and prints the received packet


// Library to make a Software UART
#include <SoftwareSerial.h>
#include <Servo.h>
#define enable 5
#define phase 6
#define FORWARD HIGH
#define BACKWARD LOW
#define BAUDRATE 9600
#define servo_pin 0
#define RX 3
#define TX 2
int reading_y;
int reading_x;
int degree;
int Speed;
#define BAUDRATE 9600
#define BTSerial Serial
Servo servo;

// Struct to hold the data we want to receive
struct Packet {
  int Y;
  int X;
} pkt; // Instantiate a Packet struct
 
void setup() {
  // Start Serial Monitor for feedback
  Serial.begin(BAUDRATE);

  // HM-10 virtual UART
  BTSerial.begin(BAUDRATE);
  servo.attach(servo_pin);
  // Set phase (digital) pin as an output
  pinMode(phase,OUTPUT);

  // Set initial condition for motor driver
//  digitalWrite(phase,FORWARD);
//  analogWrite(enable,0);
}

void loop() {{
  // Receive data from the bluetooth
  bluetooth_receive();
  reading_y = pkt.Y;
  reading_x = pkt.X;
  degree = map(reading_x,0,1023,50,105);
  servo.write(degree);

  }
  delay(10);
}

// Function responsible for receiving data over bluetooth
void bluetooth_receive() {
  // Check the software serial buffer for data to read
  if(BTSerial.available() >= sizeof(Packet)) {
    // Read in the appropriate number of bytes to fit our Packet
    BTSerial.readBytes((byte *) & pkt,sizeof(Packet));
    // Print packet (debug)
    print_packet();
  }   
}

// Function to print packet data (debug)
void print_packet() {  
  Serial.print("RX: (X,Y)=(");
  Serial.print(pkt.X); Serial.print(",");
  Serial.print(pkt.Y); Serial.print(",");
  Serial.println(")");
}

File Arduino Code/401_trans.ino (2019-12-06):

// Custom one-way communication with Bluetooth HM-10
// Transmitting data in the form of a struct to receiver
//
// Writes (hardcoded) data to the software UART 
//  and prints the transmitted packet


// Library to make a Software UART
#include <SoftwareSerial.h>

#define TX 1
#define RX 2
#define thumbstick_x A2
#define thumbstick_y A3
SoftwareSerial BTSerial(RX, TX); // (RX, TX)

#define BAUDRATE 9600

// Struct to hold the data we want to transmit
struct Packet {
  int raw_analog_reading_y;
  int raw_analog_reading_x;
} pkt; // Instantiate a Packet struct
 
void setup() {
  // Start Serial Monitor for feedback
  Serial.begin(BAUDRATE);

  // HM-10 virtual UART
  BTSerial.begin(BAUDRATE);  
}
 
void loop() {  
  // Transmit data via bluetooth
  bluetooth_transmit();  

  // Necessary forced delay, if we transmit too fast (no delay)
  //  the error rate increases
  delay(10);
}

// Function responsible for transmitting data over bluetooth
void bluetooth_transmit() {
  // Update data to be transmitted
  pkt.raw_analog_reading_y = analogRead(thumbstick_y);
  pkt.raw_analog_reading_x = analogRead(thumbstick_x);
  
  // Write packet data to the bluetooth - and transmit
  BTSerial.write((byte *) & pkt,sizeof(Packet));

  // Print packet (debug)
//  print_packet();
}

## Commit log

2019-11-09 added hardware files
    [60mmBolt.SLDPRT, BTRC DC motor.SLDPRT, BackWheelV7.STL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]
2019-12-06 Added Arduino Code
